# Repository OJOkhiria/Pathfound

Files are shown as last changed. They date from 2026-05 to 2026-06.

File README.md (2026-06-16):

# Pathfound
A custom PCB controller board and efidget that uses a Xiao RP2040 microcontroller and a MAX7219 IC to increment or decrement your clicks from 0-99 and uses them to turn on LEDS. The Xiao microcontroller provides the logic for the LEDs and the MAX7219. Specifically, by assigning the buttons to inputs on the Xiao (pressed is high and unpressed is low), you can assign high and low values to the LEDs, which are designated as outputs. 

Specifically, pressing Button1 will turn on LED1 (the rightmost one) and increase the counter. If Button2 is pressed within 2 seconds of Button1, LED2 will light up; pressing Button2 also decrements the counter. Button3 turns on LED3 (leftmost LED), but it must be held for at least 800 milliseconds. This minimim hold time also applies to the reset for the counter to allow resetting to be a little more intentional. The controller outputs this counting data to the MAX7219, which uses two seven-segment displays: one for the ones digit, and one for the tens digit. 

 The project schematics and PCB were designed in KiCad, and the firmware was programmed in C++ using the Arduino IDE. I mostly made this project to have something to fidget with on my desk. You can see the demo videos at the link below!

 https://drive.google.com/drive/folders/1nguAO52aBdsrP4bzh1c_a4cOokNBXf4z?usp=drive_link


 
Screenshot 2026-05-03 at 11 28 37 PM
Screenshot 2026-05-03 at 11 27 09 PM

Screenshot 2026-05-04 at 1 34 44 PM

BOM:

|Reference|Qty|Value|Footprint|Datasheet|
|---|---|-----|---|---|
|AFF1,AFF2|	2	|LTS-6980HR	|Display_7Segment:7SegmentLED_LTS6760_LTS6780|	http://datasheet.octopart.com/LTS-6960HR-Lite-On-datasheet-11803242.pdf|
|C1|	1	|0.1uF|Capacitor_THT:CP_Radial_D10.0mm_P2.50mm| |
|C2|	1	|10uF|Capacitor_THT:CP_Radial_D5.0mm_P2.00mm| |
|D1,D2,D3|	3|	L08R5000Q1|LED:LEDRD254W57D500H1070|	|
|R1,R2,R3|	3|	470|Resistor_THT:R_Axial_DIN0204_L3.6mm_D1.6mm_P5.08mm_Vertical| |
|R4|	1|10k|	Resistor_THT:R_Axial_DIN0204_L3.6mm_D1.6mm_P7.62mm_Horizontal| |
|SW1,SW2,SW3|	3|	SW_Push|	Button_Switch_Keyboard:SW_Cherry_MX_1.00u_PCB| |
|U1|	1|	|	XIAO:XIAO-RP2040-DIP| |
|U2|	1|	MAX7219|				|MAX7219:DIL24	https://datasheets.maximintegrated.com/en/ds/MAX7219-MAX7221.pdf|

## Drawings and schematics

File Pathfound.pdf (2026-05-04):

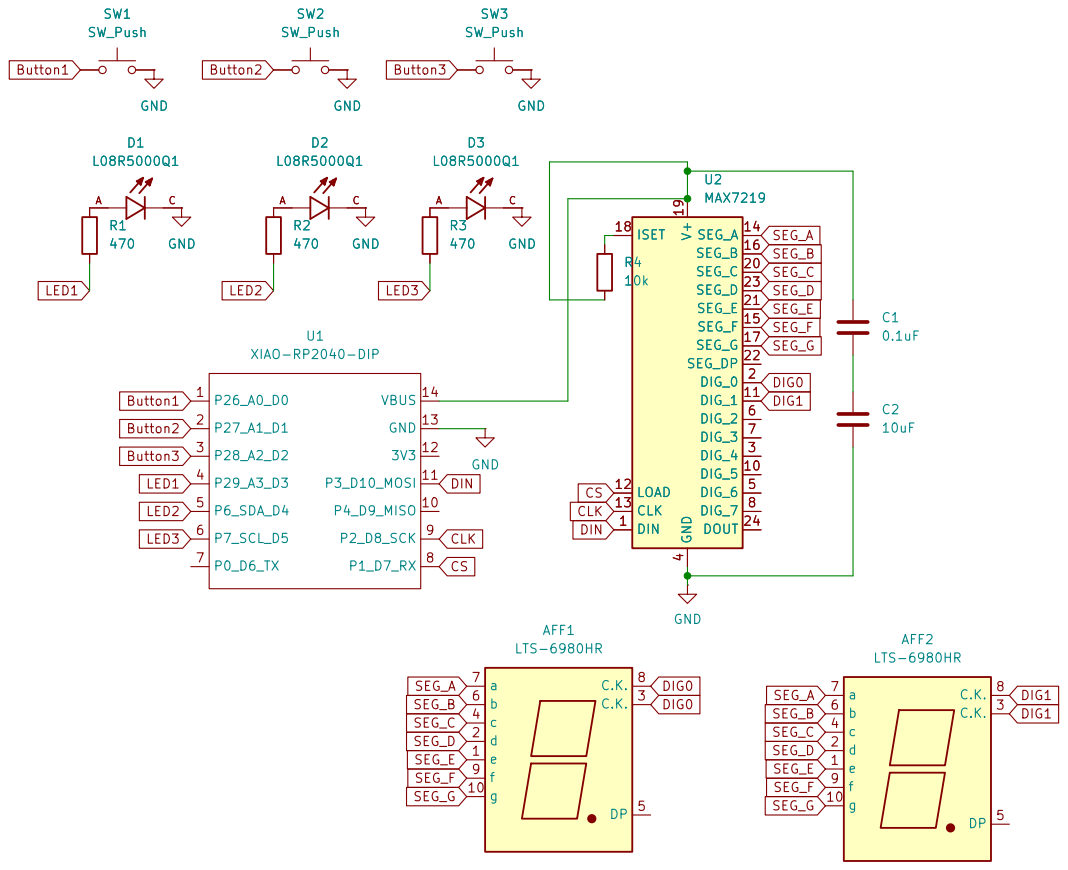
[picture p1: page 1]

Size: A4 | Rev:
KiCad E.D.A. 10.0.1 | Id: 1/1

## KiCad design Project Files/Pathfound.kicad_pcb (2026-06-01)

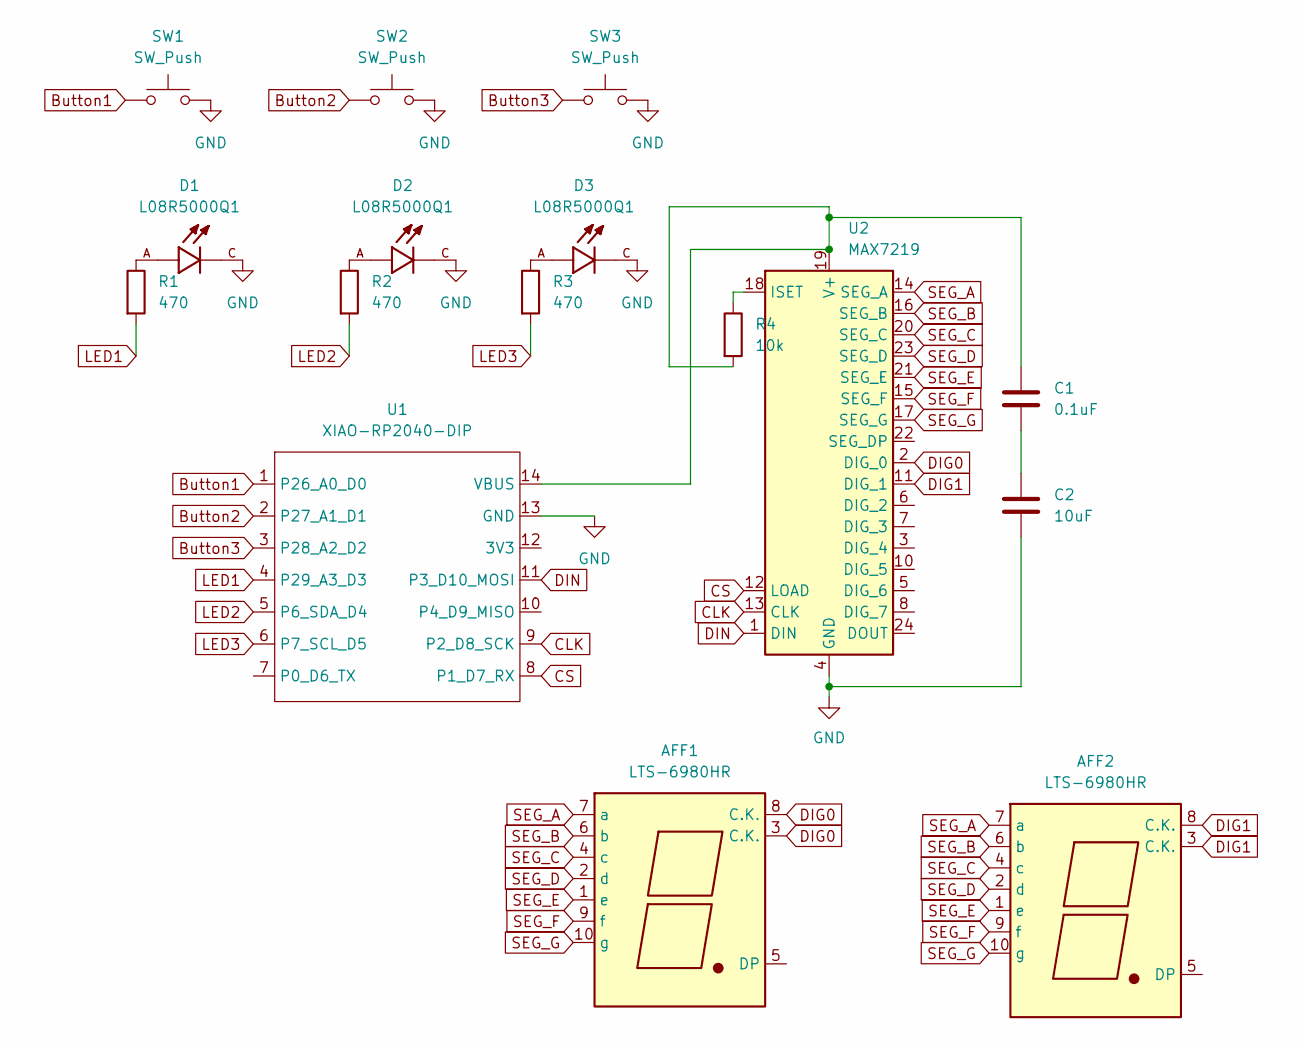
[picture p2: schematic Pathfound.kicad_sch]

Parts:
AFF1, AFF2: LTS-6980HR; 7SegmentLED_LTS6760_LTS6780
C1: 0.1uF; CP_Radial_D10.0mm_P2.50mm
C2: 10uF; CP_Radial_D5.0mm_P2.00mm
D1, D2, D3: L08R5000Q1; LEDRD254W57D500H1070; PARTREV NA
R1, R2, R3: 470; R_Axial_DIN0204_L3.6mm_D1.6mm_P5.08mm_Vertical
R4: 10k; R_Axial_DIN0204_L3.6mm_D1.6mm_P7.62mm_Horizontal
SW1, SW2, SW3: SW_Push; SW_Cherry_MX_1.00u_PCB
U1: XIAO-RP2040-DIP
U2: MAX7219; DIL24

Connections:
Button1: SW1.1, U1.1 (P26_A0_D0)
Button2: SW2.1, U1.2 (P27_A1_D1)
Button3: SW3.1, U1.3 (P28_A2_D2)
CLK: U1.9 (P2_D8_SCK), U2.13 (CLK)
CS: U1.8 (P1_D7_RX), U2.12 (LOAD)
DIG0: AFF1.3 (C.K.), AFF1.8 (C.K.), U2.2 (DIG_0)
DIG1: AFF2.3 (C.K.), AFF2.8 (C.K.), U2.11 (DIG_1)
DIN: U1.11 (P3_D10_MOSI), U2.1 (DIN)
GND: C2.2, D1.C, D2.C, D3.C, SW1.2, SW2.2, SW3.2, U1.13 (GND), U2.4 (GND), U2.9 (GND)
LED1: R1.2, U1.4 (P29_A3_D3)
LED2: R2.2, U1.5 (P6_SDA_D4)
LED3: R3.2, U1.6 (P7_SCL_D5)
unnamed: C1.2, C2.1
unnamed: D1.A, R1.1
unnamed: D2.A, R2.1
unnamed: D3.A, R3.1
unnamed: C1.1, R4.2, U1.14 (VBUS), U2.19 (V+)
unnamed: R4.1, U2.18 (ISET)
SEG_A: AFF1.7 (a), AFF2.7 (a), U2.14 (SEG_A)
SEG_B: AFF1.6 (b), AFF2.6 (b), U2.16 (SEG_B)
SEG_C: AFF1.4 (c), AFF2.4 (c), U2.20 (SEG_C)
SEG_D: AFF1.2 (d), AFF2.2 (d), U2.23 (SEG_D)
SEG_E: AFF1.1 (e), AFF2.1 (e), U2.21 (SEG_E)
SEG_F: AFF1.9 (f), AFF2.9 (f), U2.15 (SEG_F)
SEG_G: AFF1.10 (g), AFF2.10 (g), U2.17 (SEG_G)

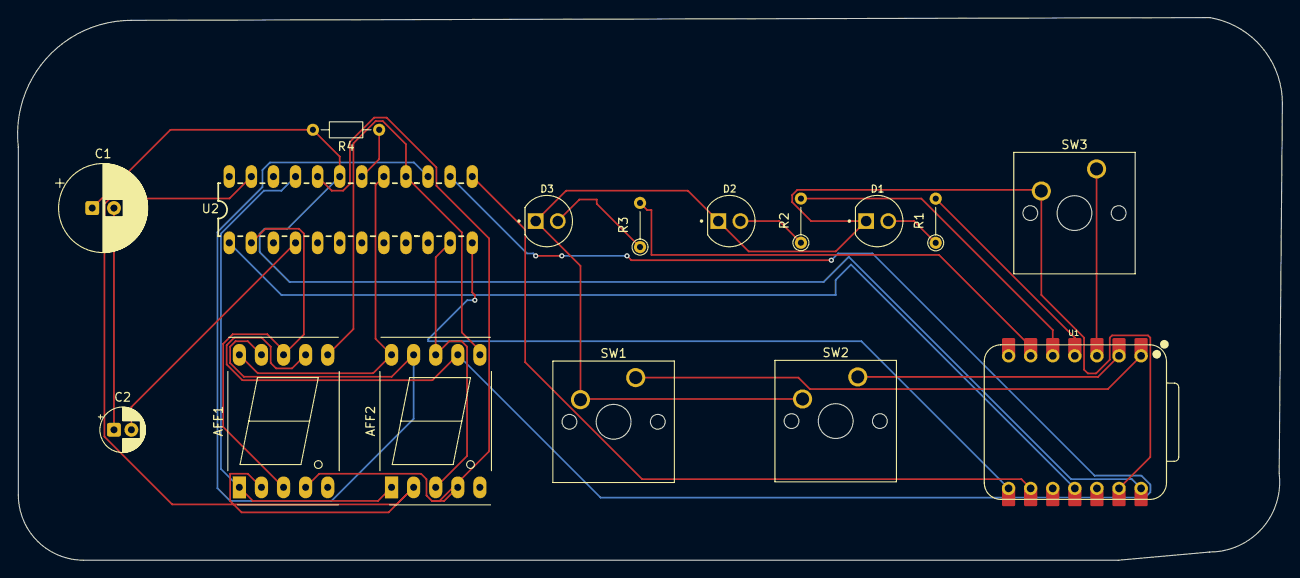
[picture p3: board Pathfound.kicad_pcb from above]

Board: 2 copper layers, 145.5 x 62.4 mm, 16 parts (0 on the bottom side), 25 nets.

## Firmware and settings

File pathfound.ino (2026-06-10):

#include <Arduino.h>

const int BUT1 = D0;  // Increment
const int BUT2 = D1;  // Decrement
const int BUT3 = D2;  // Reset (hold 800 ms)

const int LED1 = D3;
const int LED2 = D4;
const int LED3 = D5;

const int DIN_PIN = D10;
const int CLK_PIN = D8;
const int CS_PIN  = D7;

int count = 0;

// Increment debounce
int lastIncReading = HIGH;
int incState = HIGH;
unsigned long lastIncDebounceTime = 0;

// Decrement debounce
int lastDecReading = HIGH;
int decState = HIGH;
unsigned long lastDecDebounceTime = 0;

const unsigned long debounceDelay = 50;

// Timing variables
unsigned long lastBut1Time = 0;
unsigned long lastBut2Time = 0;
unsigned long but3PressStart = 0;

bool resetPerformed = false;

void sendToMax7219(uint8_t opcode, uint8_t data) {
  digitalWrite(CS_PIN, LOW);
  shiftOut(DIN_PIN, CLK_PIN, MSBFIRST, opcode);
  shiftOut(DIN_PIN, CLK_PIN, MSBFIRST, data);
  digitalWrite(CS_PIN, HIGH);
}

void initDisplay() {
  pinMode(DIN_PIN, OUTPUT);
  pinMode(CLK_PIN, OUTPUT);
  pinMode(CS_PIN, OUTPUT);

  digitalWrite(DIN_PIN, LOW);
  digitalWrite(CLK_PIN, LOW);
  digitalWrite(CS_PIN, HIGH);

  sendToMax7219(0x0F, 0x00);
  sendToMax7219(0x0C, 0x01);
  sendToMax7219(0x0B, 0x01);
  sendToMax7219(0x09, 0xFF);
  sendToMax7219(0x0A, 0x08);

  sendToMax7219(1, 0x0F);
  sendToMax7219(2, 0x0F);
}

void clearDisplay() {
  sendToMax7219(1, 0x0F);
  sendToMax7219(2, 0x0F);
}

void showStartupTest() {
  sendToMax7219(1, 8);
  sendToMax7219(2, 8);
  delay(500);

  sendToMax7219(1, 1);
  sendToMax7219(2, 2);
  delay(500);

  clearDisplay();
}

void displayCount(int value) {
  value = constrain(value, 0, 99);

  uint8_t tens = value / 10;
  uint8_t ones = value % 10;

  if (value < 10) {
    sendToMax7219(1, 0x0F);
  } else {
    sendToMax7219(1, tens);
  }

  sendToMax7219(2, ones);
}

void setup() {
  pinMode(BUT1, INPUT_PULLUP);
  pinMode(BUT2, INPUT_PULLUP);
  pinMode(BUT3, INPUT_PULLUP);

  pinMode(LED1, OUTPUT);
  pinMode(LED2, OUTPUT);
  pinMode(LED3, OUTPUT);

  initDisplay();
  showStartupTest();
  displayCount(count);
}

void loop() {
  unsigned long now = millis();

  int but1Reading = digitalRead(BUT1);
  int but2Reading = digitalRead(BUT2);
  int but3Reading = digitalRead(BUT3);

  // LED1 and LED2 follow button presses
  digitalWrite(LED1, but1Reading == LOW);
  digitalWrite(LED2, but2Reading == LOW);

  // --------------------
  // BUT3 hold-to-reset
  // --------------------
  if (but3Reading == LOW) {
    if (but3PressStart == 0) {
      but3PressStart = now;
      resetPerformed = false;
    }

    if ((now - but3PressStart) >= 800) {
      digitalWrite(LED3, HIGH);

      if (!resetPerformed) {
        count = 0;
        displayCount(count);
        resetPerformed = true;
      }
    } else {
      digitalWrite(LED3, LOW);
    }
  } else {
    but3PressStart = 0;
    resetPerformed = false;
    digitalWrite(LED3, LOW);
  }

  // --------------------
  // Increment (BUT1)
  // --------------------
  if (but1Reading != lastIncReading) {
    lastIncDebounceTime = now;
  }

  if ((now - lastIncDebounceTime) > debounceDelay) {
    if (but1Reading != incState) {
      incState = but1Reading;

      if (incState == LOW) {
        count = (count + 1) % 100;
        displayCount(count);
        lastBut1Time = now;
      }
    }
  }

  lastIncReading = but1Reading;

  // --------------------
  // Decrement (BUT2)
  // --------------------
  if (but2Reading != lastDecReading) {
    lastDecDebounceTime = now;
  }

  if ((now - lastDecDebounceTime) > debounceDelay) {
    if (but2Reading != decState) {
      decState = but2Reading;

      if (decState == LOW) {
        if (count > 0) {
          count--;
        } else {
          count = 99;
        }

        displayCount(count);
        lastBut2Time = now;
      }
    }
  }

  lastDecReading = but2Reading;

  // --------------------
  // LED2 bonus indicator
  // --------------------
  unsigned long diff =
      (lastBut1Time > lastBut2Time)
          ? (lastBut1Time - lastBut2Time)
          : (lastBut2Time - lastBut1Time);

  if (lastBut1Time != 0 &&
      lastBut2Time != 0 &&
      diff <= 2000) {
    digitalWrite(LED2, HIGH);
  }
}

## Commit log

2026-06-15 Refactor BOM section to use Markdown table format
    Updated BOM table format to Markdown style.
2026-06-16 Format BOM table in README.md
2026-06-16 Enhance README with detailed button functionality
    Expanded the description of button functionalities and clarified the project details.
